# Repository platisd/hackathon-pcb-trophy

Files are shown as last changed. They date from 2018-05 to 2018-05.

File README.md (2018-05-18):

# Hackathon PCB trophy
A cool trophy for the winners of your Hackathon

trophies

## What?
This repository includes the necessary software and hardware schematics and layout files to create some trophy-shaped boards that can be given as awards to the winners of a competition/hackathon/task/you-name-it.

The trophies have are programmable, using the ATTiny85 microcontroller and have the ability to play a tune once a button is pressed.

## Why?
As someone who often gets involved in organizing hackathons I had to come up with cool looking trophies for our competitions' winners. 3D printed trophies take too long to be produced and assembled so I resorted to a different option: PCBs. Compared to the 3D printed trophies, a PCB is more durable, can be assembled faster, requires less equipment from your side (i.e. no printer needed) and looks - if not more - then equally as cool. More importantly, the trophy is programmable and has the potential to spark interest in electronics and hardware.

## How?
The circuit as well as the code are relatively straight forward. A microcontroller (ATTiny85) is connected to a buzzer and a tactile button is connected to the microcontroller's reset pin, causing the firmware to reboot every time it is pressed. Everything is powered up by a CR2032 coin cell battery.

fritzing circuit

On the software-side, the microcontroller plays an [RTTTL](https://en.wikipedia.org/wiki/Ring_Tone_Transfer_Language) tune (the [theme song from Rocky](https://www.youtube.com/watch?v=DhlPAj38rHc)) and then goes to deep sleep to preserve power. The RTTTL tune is played using code written by Brett Hagman from [Rogue Robotics](http://www.roguerobotics.com/).

### Components
* Hackathon trophy PCB ([Order it from PCBway.com](https://www.pcbway.com/project/shareproject/Hackathon_trophy.html))
* ATTiny85-20PU
* 12mm buzzer
* 4.7KΩ pull-up resistor
* 22Ω current limiting resistor
* 2032 coin cell battery holder
* 2032 coin cell battery

## Media
* [PCB trophies for your Hackathon](https://platis.solutions/blog/2018/05/16/pcb-trophies-for-your-hackathon/)
* [PCB trophies demo video](https://www.youtube.com/watch?v=lDynO2vfTys)

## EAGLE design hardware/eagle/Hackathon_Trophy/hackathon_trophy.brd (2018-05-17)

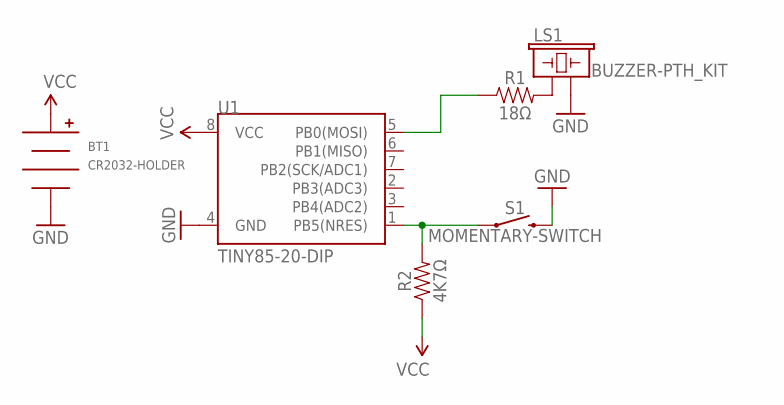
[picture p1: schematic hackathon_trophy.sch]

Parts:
BT1: CR2032-HOLDER; CH28-2032LF
LS1: BUZZER-PTH_KIT; BUZZER-12MM-KIT
R1: 18Ω; 1206
R2: 4K7Ω; 1206
S1: MOMENTARY-SWITCH; TACTILE_SWITCH_PTH_6.0MM_KIT
U1: TINY85-20-DIP; DIP08_MCU

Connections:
GND: BT1.NEG, LS1.- (2), S1.3 (2), U1.4 (GND)
unnamed: R2.2, S1.1, U1.1 (PB5(NRES))
unnamed: LS1.+ (1), R1.2
unnamed: R1.1, U1.5 (PB0(MOSI))
VCC: BT1.POS, R2.1, U1.8 (VCC)

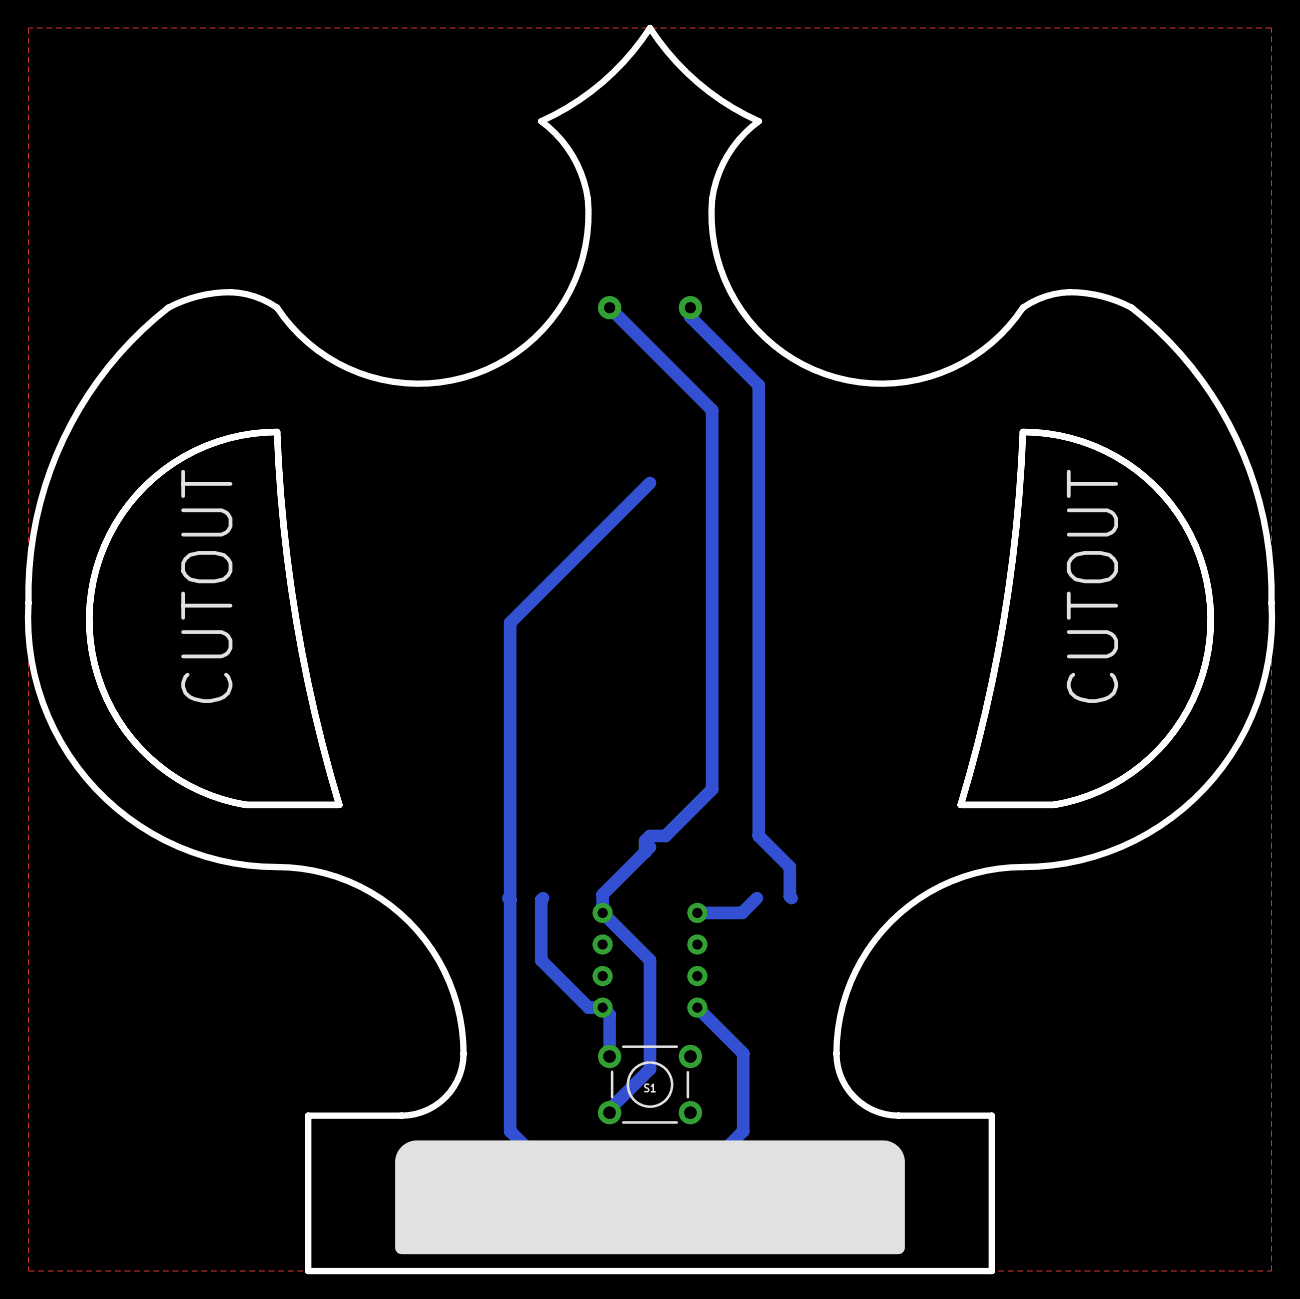
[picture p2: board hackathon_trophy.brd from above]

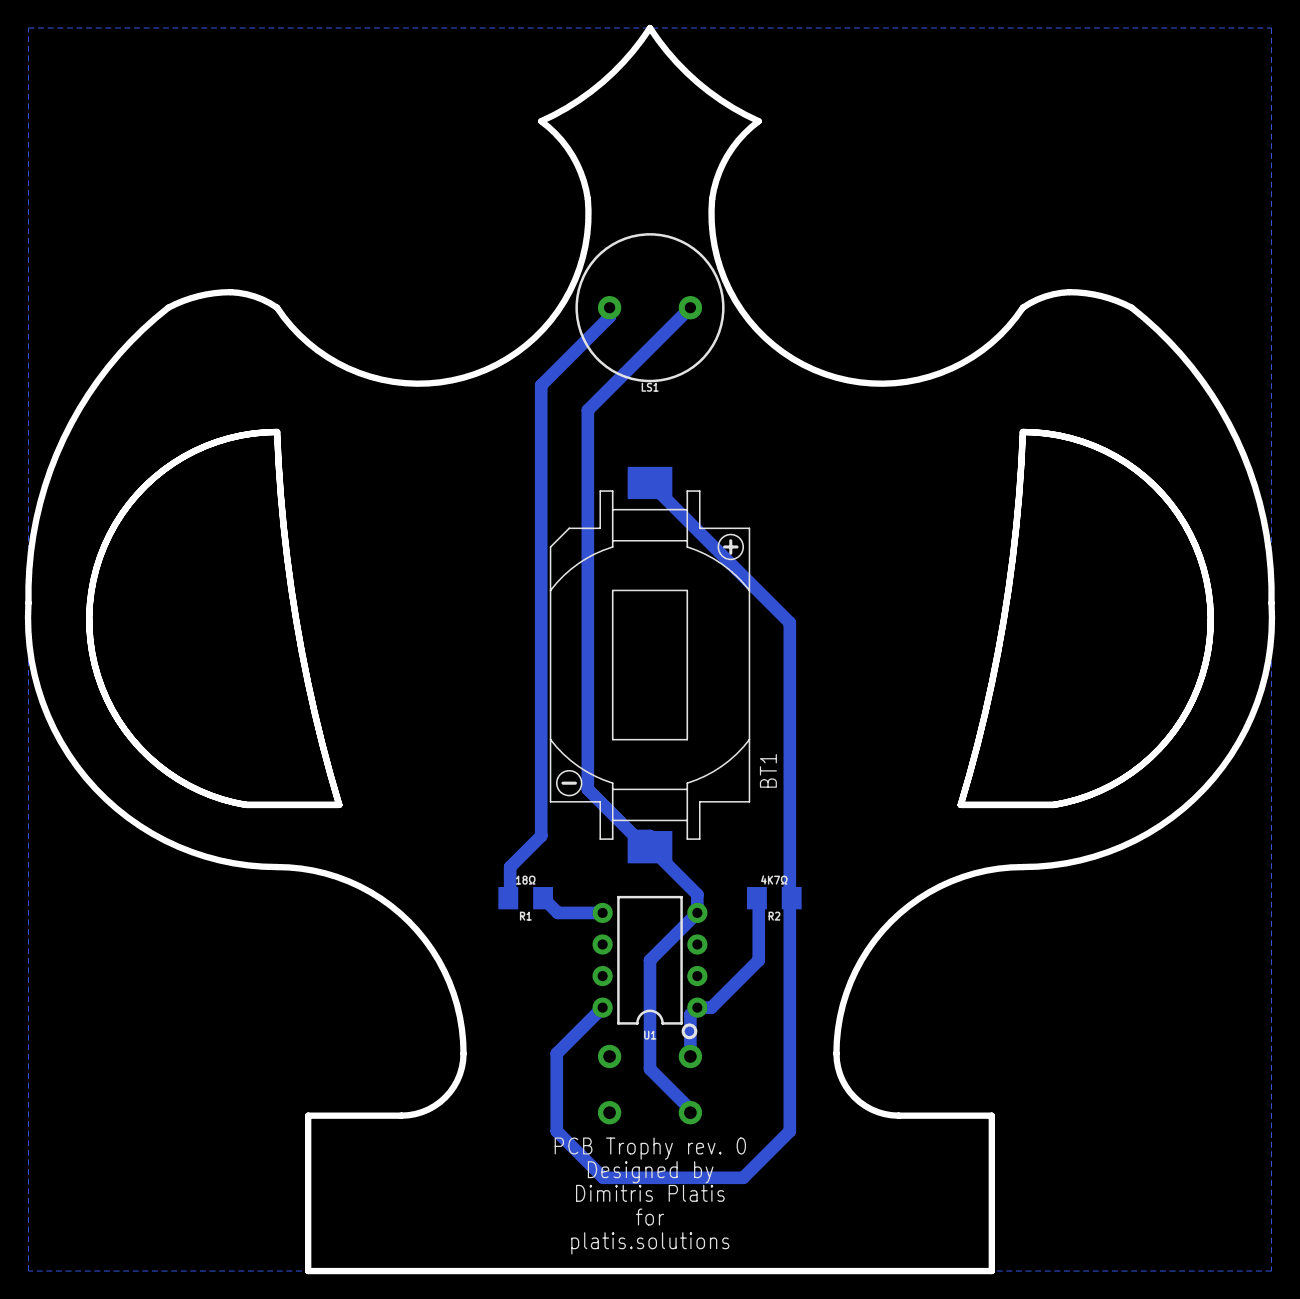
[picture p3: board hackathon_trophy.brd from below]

Board: 2 copper layers, 100.1 x 100.0 mm, 6 parts (5 on the bottom side), 5 nets.

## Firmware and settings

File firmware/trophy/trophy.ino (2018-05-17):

// A fun sketch to demonstrate the use of the tone() function written by Brett Hagman.

// This plays RTTTL (RingTone Text Transfer Language) songs using the
// now built-in tone() command in Wiring and Arduino.
// Written by Brett Hagman
// http://www.roguerobotics.com/

#include <avr/sleep.h>
#include <avr/power.h>
#include <avr/wdt.h>

const int tonePin = PB0;

#define OCTAVE_OFFSET 0

// These values can also be found as constants in the Tone library (Tone.h)
int notes[] = { 0,
                262, 277, 294, 311, 330, 349, 370, 392, 415, 440, 466, 494,
                523, 554, 587, 622, 659, 698, 740, 784, 831, 880, 932, 988,
                1047, 1109, 1175, 1245, 1319, 1397, 1480, 1568, 1661, 1760, 1865, 1976,
                2093, 2217, 2349, 2489, 2637, 2794, 2960, 3136, 3322, 3520, 3729, 3951
              };

//char *song = "The Simpsons:d=4,o=5,b=160:c.6,e6,f#6,8a6,g.6,e6,c6,8a,8f#,8f#,8f#,2g,8p,8p,8f#,8f#,8f#,8g,a#.,8c6,8c6,8c6,c6";
//char *song = "Indiana:d=4,o=5,b=250:e,8p,8f,8g,8p,1c6,8p.,d,8p,8e,1f,p.,g,8p,8a,8b,8p,1f6,p,a,8p,8b,2c6,2d6,2e6,e,8p,8f,8g,8p,1c6,p,d6,8p,8e6,1f.6,g,8p,8g,e.6,8p,d6,8p,8g,e.6,8p,d6,8p,8g,f.6,8p,e6,8p,8d6,2c6";
//char *song = "TakeOnMe:d=4,o=4,b=160:8f#5,8f#5,8f#5,8d5,8p,8b,8p,8e5,8p,8e5,8p,8e5,8g#5,8g#5,8a5,8b5,8a5,8a5,8a5,8e5,8p,8d5,8p,8f#5,8p,8f#5,8p,8f#5,8e5,8e5,8f#5,8e5,8f#5,8f#5,8f#5,8d5,8p,8b,8p,8e5,8p,8e5,8p,8e5,8g#5,8g#5,8a5,8b5,8a5,8a5,8a5,8e5,8p,8d5,8p,8f#5,8p,8f#5,8p,8f#5,8e5,8e5";
//char *song = "Entertainer:d=4,o=5,b=140:8d,8d#,8e,c6,8e,c6,8e,2c.6,8c6,8d6,8d#6,8e6,8c6,8d6,e6,8b,d6,2c6,p,8d,8d#,8e,c6,8e,c6,8e,2c.6,8p,8a,8g,8f#,8a,8c6,e6,8d6,8c6,8a,2d6";
//char *song = "Muppets:d=4,o=5,b=250:c6,c6,a,b,8a,b,g,p,c6,c6,a,8b,8a,8p,g.,p,e,e,g,f,8e,f,8c6,8c,8d,e,8e,8e,8p,8e,g,2p,c6,c6,a,b,8a,b,g,p,c6,c6,a,8b,a,g.,p,e,e,g,f,8e,f,8c6,8c,8d,e,8e,d,8d,c";
//char *song = "Xfiles:d=4,o=5,b=125:e,b,a,b,d6,2b.,1p,e,b,a,b,e6,2b.,1p,g6,f#6,e6,d6,e6,2b.,1p,g6,f#6,e6,d6,f#6,2b.,1p,e,b,a,b,d6,2b.,1p,e,b,a,b,e6,2b.,1p,e6,2b.";
//char *song = "Looney:d=4,o=5,b=140:32p,c6,8f6,8e6,8d6,8c6,a.,8c6,8f6,8e6,8d6,8d#6,e.6,8e6,8e6,8c6,8d6,8c6,8e6,8c6,8d6,8a,8c6,8g,8a#,8a,8f";
//char *song = "20thCenFox:d=16,o=5,b=140:b,8p,b,b,2b,p,c6,32p,b,32p,c6,32p,b,32p,c6,32p,b,8p,b,b,b,32p,b,32p,b,32p,b,32p,b,32p,b,32p,b,32p,g#,32p,a,32p,b,8p,b,b,2b,4p,8e,8g#,8b,1c#6,8f#,8a,8c#6,1e6,8a,8c#6,8e6,1e6,8b,8g#,8a,2b";
//char *song = "Bond:d=4,o=5,b=80:32p,16c#6,32d#6,32d#6,16d#6,8d#6,16c#6,16c#6,16c#6,16c#6,32e6,32e6,16e6,8e6,16d#6,16d#6,16d#6,16c#6,32d#6,32d#6,16d#6,8d#6,16c#6,16c#6,16c#6,16c#6,32e6,32e6,16e6,8e6,16d#6,16d6,16c#6,16c#7,c.7,16g#6,16f#6,g#.6";
//char *song = "MASH:d=8,o=5,b=140:4a,4g,f#,g,p,f#,p,g,p,f#,p,2e.,p,f#,e,4f#,e,f#,p,e,p,4d.,p,f#,4e,d,e,p,d,p,e,p,d,p,2c#.,p,d,c#,4d,c#,d,p,e,p,4f#,p,a,p,4b,a,b,p,a,p,b,p,2a.,4p,a,b,a,4b,a,b,p,2a.,a,4f#,a,b,p,d6,p,4e.6,d6,b,p,a,p,2b";
//char *song = "StarWars:d=4,o=5,b=45:32p,32f#,32f#,32f#,8b.,8f#.6,32e6,32d#6,32c#6,8b.6,16f#.6,32e6,32d#6,32c#6,8b.6,16f#.6,32e6,32d#6,32e6,8c#.6,32f#,32f#,32f#,8b.,8f#.6,32e6,32d#6,32c#6,8b.6,16f#.6,32e6,32d#6,32c#6,8b.6,16f#.6,32e6,32d#6,32e6,8c#6";
//char *song = "GoodBad:d=4,o=5,b=56:32p,32a#,32d#6,32a#,32d#6,8a#.,16f#.,16g#.,d#,32a#,32d#6,32a#,32d#6,8a#.,16f#.,16g#.,c#6,32a#,32d#6,32a#,32d#6,8a#.,16f#.,32f.,32d#.,c#,32a#,32d#6,32a#,32d#6,8a#.,16g#.,d#";
//char *song = "TopGun:d=4,o=4,b=31:32p,16c#,16g#,16g#,32f#,32f,32f#,32f,16d#,16d#,32c#,32d#,16f,32d#,32f,16f#,32f,32c#,16f,d#,16c#,16g#,16g#,32f#,32f,32f#,32f,16d#,16d#,32c#,32d#,16f,32d#,32f,16f#,32f,32c#,g#";
//char *song = "A-Team:d=8,o=5,b=125:4d#6,a#,2d#6,16p,g#,4a#,4d#.,p,16g,16a#,d#6,a#,f6,2d#6,16p,c#.6,16c6,16a#,g#.,2a#";
//char *song = "Flinstones:d=4,o=5,b=40:32p,16f6,16a#,16a#6,32g6,16f6,16a#.,16f6,32d#6,32d6,32d6,32d#6,32f6,16a#,16c6,d6,16f6,16a#.,16a#6,32g6,16f6,16a#.,32f6,32f6,32d#6,32d6,32d6,32d#6,32f6,16a#,16c6,a#,16a6,16d.6,16a#6,32a6,32a6,32g6,32f#6,32a6,8g6,16g6,16c.6,32a6,32a6,32g6,32g6,32f6,32e6,32g6,8f6,16f6,16a#.,16a#6,32g6,16f6,16a#.,16f6,32d#6,32d6,32d6,32d#6,32f6,16a#,16c.6,32d6,32d#6,32f6,16a#,16c.6,32d6,32d#6,32f6,16a#6,16c7,8a#.6";
//char *song = "Jeopardy:d=4,o=6,b=125:c,f,c,f5,c,f,2c,c,f,c,f,a.,8g,8f,8e,8d,8c#,c,f,c,f5,c,f,2c,f.,8d,c,a#5,a5,g5,f5,p,d#,g#,d#,g#5,d#,g#,2d#,d#,g#,d#,g#,c.7,8a#,8g#,8g,8f,8e,d#,g#,d#,g#5,d#,g#,2d#,g#.,8f,d#,c#,c,p,a#5,p,g#.5,d#,g#";
//char *song = "Gadget:d=16,o=5,b=50:32d#,32f,32f#,32g#,a#,f#,a,f,g#,f#,32d#,32f,32f#,32g#,a#,d#6,4d6,32d#,32f,32f#,32g#,a#,f#,a,f,g#,f#,8d#";
//char *song = "Smurfs:d=32,o=5,b=200:4c#6,16p,4f#6,p,16c#6,p,8d#6,p,8b,p,4g#,16p,4c#6,p,16a#,p,8f#,p,8a#,p,4g#,4p,g#,p,a#,p,b,p,c6,p,4c#6,16p,4f#6,p,16c#6,p,8d#6,p,8b,p,4g#,16p,4c#6,p,16a#,p,8b,p,8f,p,4f#";
//char *song = "MahnaMahna:d=16,o=6,b=125:c#,c.,b5,8a#.5,8f.,4g#,a#,g.,4d#,8p,c#,c.,b5,8a#.5,8f.,g#.,8a#.,4g,8p,c#,c.,b5,8a#.5,8f.,4g#,f,g.,8d#.,f,g.,8d#.,f,8g,8d#.,f,8g,d#,8c,a#5,8d#.,8d#.,4d#,8d#.";
//char *song = "LeisureSuit:d=16,o=6,b=56:f.5,f#.5,g.5,g#5,32a#5,f5,g#.5,a#.5,32f5,g#5,32a#5,g#5,8c#.,a#5,32c#,a5,a#.5,c#.,32a5,a#5,32c#,d#,8e,c#.,f.,f.,f.,f.,f,32e,d#,8d,a#.5,e,32f,e,32f,c#,d#.,c#";
//char *song = "MissionImp:d=16,o=6,b=95:32d,32d#,32d,32d#,32d,32d#,32d,32d#,32d,32d,32d#,32e,32f,32f#,32g,g,8p,g,8p,a#,p,c7,p,g,8p,g,8p,f,p,f#,p,g,8p,g,8p,a#,p,c7,p,g,8p,g,8p,f,p,f#,p,a#,g,2d,32p,a#,g,2c#,32p,a#,g,2c,a#5,8c,2p,32p,a#5,g5,2f#,32p,a#5,g5,2f,32p,a#5,g5,2e,d#,8d";
//char *song = "ChariotsofFire:d=16,o=5,b=85:8c#,f#.,g#.,a#.,4g#,4f,8p,8c#,f#.,g#.,a#.,2g#,8p,8c#,f#.,g#.,a#.,4g#,4f,8p,8f,f#.,f.,c#.,2c#";
//char *song = "JingleBells:d=4,o=5,b=170:b,b,b,p,b,b,b,p,b,d6,g.,8a,2b.,8p,c6,c6,c6.,8c6,c6,b,b,8b,8b,b,a,a,b,2a,2d6,b,b,b,p,b,b,b,p,b,d6,g.,8a,2b.,8p,c6,c6,c6.,8c6,c6,b,b,8b,8b,b,a,a,b,2a,2d6";
char *song = "RockyFilm:d=4,o=5,b=112:16e,8g.,2a.,16a,8b.,2e.,16e,8g.,2a.,16a,8b.,1e,8p,16d,16c,8d.,16c,16d,2e,16c,16c,8b5,16b5,16a5,16p,16a5,g5";
/**
   Sets the MCU into a deep sleep state until a change interrupt is triggered
*/
void goToSleep() {
  set_sleep_mode(SLEEP_MODE_PWR_DOWN);
  power_all_disable (); // power off ADC, Timer 0 and 1, serial interface
  sleep_enable();
  sleep_cpu(); // Sleep here and wait for the interrupt
  sleep_disable();
  power_all_enable(); // power everything back on
}

void setup(void)
{
  ADCSRA = 0; // turn off ADC
}

#define isdigit(n) (n >= '0' && n <= '9')

void play_rtttl(char *p)
{
  // Absolutely no error checking in here

  byte default_dur = 4;
  byte default_oct = 6;
  int bpm = 63;
  int num;
  long wholenote;
  long duration;
  byte note;
  byte scale;

  // format: d=N,o=N,b=NNN:
  // find the start (skip name, etc)

  while (*p != ':') p++;   // ignore name
  p++;                     // skip ':'

  // get default duration
  if (*p == 'd')
  {
    p++; p++;              // skip "d="
    num = 0;
    while (isdigit(*p))
    {
      num = (num * 10) + (*p++ - '0');
    }
    if (num > 0) default_dur = num;
    p++;                   // skip comma
  }

  // get default octave
  if (*p == 'o')
  {
    p++; p++;              // skip "o="
    num = *p++ - '0';
    if (num >= 3 && num <= 7) default_oct = num;
    p++;                   // skip comma
  }

  // get BPM
  if (*p == 'b')
  {
    p++; p++;              // skip "b="
    num = 0;
    while (isdigit(*p))
    {
      num = (num * 10) + (*p++ - '0');
    }
    bpm = num;
    p++;                   // skip colon
  }

  // BPM usually expresses the number of quarter notes per minute
  wholenote = (60 * 1000L / bpm) * 4;  // this is the time for whole note (in milliseconds)

  // now begin note loop
  while (*p)
  {
    // first, get note duration, if available
    num = 0;
    while (isdigit(*p))
    {
      num = (num * 10) + (*p++ - '0');
    }

    if (num) duration = wholenote / num;
    else duration = wholenote / default_dur;  // we will need to check if we are a dotted note after

    // now get the note
    note = 0;

    switch (*p)
    {
      case 'c':
        note = 1;
        break;
      case 'd':
        note = 3;
        break;
      case 'e':
        note = 5;
        break;
      case 'f':
        note = 6;
        break;
      case 'g':
        note = 8;
        break;
      case 'a':
        note = 10;
        break;
      case 'b':
        note = 12;
        break;
      case 'p':
      default:
        note = 0;
    }
    p++;

    // now, get optional '#' sharp
    if (*p == '#')
    {
      note++;
      p++;
    }

    // now, get optional '.' dotted note
    if (*p == '.')
    {
      duration += duration / 2;
      p++;
    }

    // now, get scale
    if (isdigit(*p))
    {
      scale = *p - '0';
      p++;
    }
    else
    {
      scale = default_oct;
    }

    scale += OCTAVE_OFFSET;

    if (*p == ',')
      p++;       // skip comma for next note (or we may be at the end)

    // now play the note

    if (note)
    {
      tone(tonePin, notes[(scale - 4) * 12 + note]);
      delay(duration);
    }
    else
    {
      delay(duration);
    }
  }
}

void loop(void)
{
  play_rtttl(song);
  play_rtttl(song);
  goToSleep();
}

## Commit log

2018-05-17 Add Arduino sketch
2018-05-17 Add rev.0 Eagle CAD schematics
    [hackathon_trophy.brd, hackathon_trophy.sch]
2018-05-18 Fix circuit schematic
    The pull up was connected in series

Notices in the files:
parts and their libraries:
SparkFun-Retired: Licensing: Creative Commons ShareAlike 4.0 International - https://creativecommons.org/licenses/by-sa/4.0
